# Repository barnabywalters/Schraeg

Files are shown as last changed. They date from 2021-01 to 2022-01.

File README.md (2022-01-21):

# Schräg

Schräg is an 8HP multimode filter module for the eurorack format, based off the [Bastl Cinnamon](https://bastl-instruments.com/eurorack/modules/cinnamon).

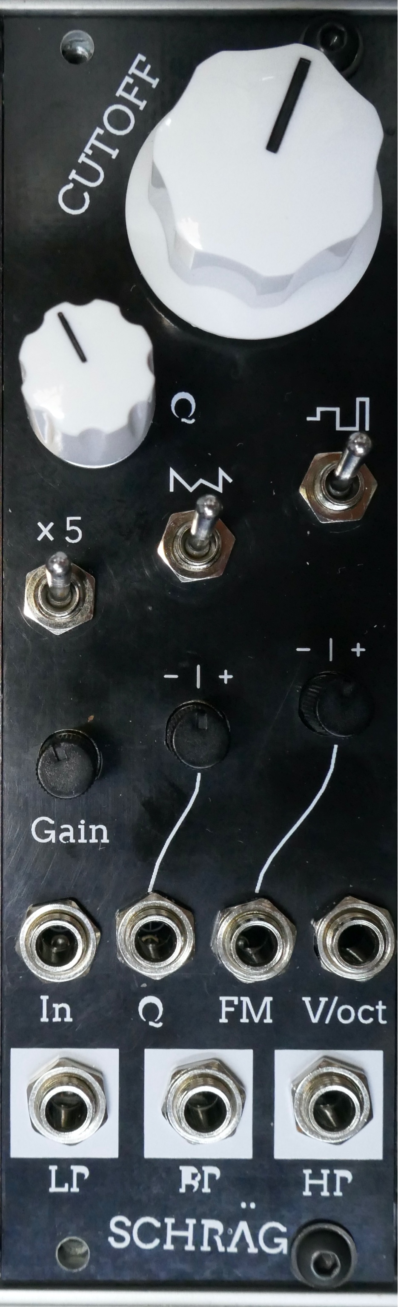
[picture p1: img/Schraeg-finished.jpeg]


## Smaller Warning and Disclaimer

As of 2021-03-01, at least one person has reported successfully building the current board revision. However, another builder reported a minor issue with the attenuverter circuits which prevents full-range voltage control over resonance (and limits voltage control over FM). This should be fixable only with component substitutions, we’re working on a fix. More information and updates [in the corresponding lines thread](https://llllllll.co/t/diy-module-release-schrag-bastl-cinnamon-rework/40590).

See the Changelog below for more updates and version-specific fixes.

## Quick links

* [Schematic](Schraeg/Schraeg.pdf)
* [Gerbers](Schraeg/output)
* [BOM](Schraeg/Schraeg%20BOM.csv)
* [Schräg on ModularGrid](https://www.modulargrid.net/e/other-unknown-schraeg)
* [Schräg release and Q&A thread on lines](https://llllllll.co/t/diy-module-release-schrag-bastl-cinnamon-rework/40590)

## Need help assembling your Schräg?

I can’t promise quick responses, but am happy to try to help out!

If you’re **having trouble or need help assembling or troubleshooting** a Schräg, please start a [discussion](https://github.com/barnabywalters/Schraeg/discussions/new).

If you’ve **found a specific error which needs fixing**, please file an [issue](https://github.com/barnabywalters/Schraeg/issues/new).

If you’re not sure which, start a discussion, and we’ll convert it into an issue if we can distill it into a concrete problem.

## Features

Schräg is effectively a repackaged Bastl Cinnamon:

* Multimode filter with independent outputs (2-pole LP, 2-pole HP, 1-pole BP)
* V/oct input
* Self-resonates for use as a sine oscillator
* Input with an attenuator and 5x gain switch
* Two character switches for altering the resonance tracking
* All-SMD construction in a DIY-friendly format, with 0603 handsoldering footprints, all components on the back of the circuit board
* Built mostly using standard and easily-available components

with a few modifications:

* larger 8HP form factor, allowing for a big juicy cutoff knob and larger character and gain switches
* Voltage control over resonance, through an attenuverter
* FM input through an attenuverter, which works as a pitch fine-tune control with nothing patched
* A bi-directional power connector, with polyfuses
* An Interactive BOM (`Schraeg/Output/Interactive BOM.html` once you’ve cloned the repo locally) to aid in part placement
* Schematics and PCB laid out using KiCAD

The additional functionality is achieved with a minimum of extra components, thanks to the two unused VCA cells in the original design.

## License

The schematic, board layout and graphics are released under a cc-by-sa license. [Bastl Instruments](https://bastl-instruments.com/) generously gave their permission for me to release my rework of their module. They’re a cool company. Go check out their work!

## Development

In 2019 I was looking through the [Bastl Cinnamon schematic](https://github.com/bastl-instruments/bastlSchematics/blob/master/CINNAMON_V1.2.pdf) and realised that it only uses two of the four available V2164D VCA cells.

At the time I needed PCB layout practise (and a filter module for my DIY eurorack!), so I ended up prototyping and building an 8HP version of cinnamon for myself which uses the two spare cells to implement voltage control over resonance, as well as a few other little additions listed above.

I called it “Schräg” because of both the angled panel design, the weird sounds possible with Bastl’s cool distortion circuits, and the strange way KiCAD mangled the panel graphics.

A bit more than a year after building the first Schräg, I finally got around to fixing the various small issues with the first board revision, and asking Bastl if they were okay with me open-sourcing the project. They were, and here we are.

## Changelog

### v0.2.1

* Fixed the LM4040 schematic symbols and PCB traces (#2)

### v0.2

* First version released to the public.
* These boards have an issue with the LM4040 orientation (see #2). Depending on the specific LM4040s, it may not cause any problems, but if building from scratch it’s best to install them correctly the first time. To fix it, solder the LM4040s at an angle so that pin 2 (NC) gets connected to pin 3 (5V Ref or GND, depending on the LM4040)

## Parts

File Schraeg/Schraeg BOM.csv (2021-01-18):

Reference | Quantity | Value | Footprint | Datasheet | Notes
AUDIO_IN1 BP_OUT1 FM_IN1 HP_OUT1 LP_OUT1 RES_CV1 V_OCT_IN1 | 7 | PJ301M-12 | Eurocad:PJ301M-12
C1 C12 C7 C8 | 4 | 560pF | Capacitor_SMD:C_0603_1608Metric_Pad1.05x0.95mm_HandSolder | ~
C10 C11 C13 | 3 | 220pF | Capacitor_SMD:C_0603_1608Metric_Pad1.05x0.95mm_HandSolder | ~
C14 C15 C18 | 3 | 220n | Capacitor_SMD:C_0603_1608Metric_Pad1.05x0.95mm_HandSolder | ~
C16 C17 | 2 | 22uF | Capacitor_SMD:CP_Elec_6.3x5.4 | ~
C19 C20 C21 C22 C23 C24 C25 C26 C27 C28 | 10 | 100n | Capacitor_SMD:C_0603_1608Metric_Pad1.05x0.95mm_HandSolder | ~
C2 C4 C5 C6 | 4 | 10uF | Capacitor_SMD:CP_Elec_5x4.5 | ~
C3 C9 | 2 | 100pF | Capacitor_SMD:C_0603_1608Metric_Pad1.05x0.95mm_HandSolder | ~
D1 D2 | 2 | 1N4148 | Diode_SMD:D_SOD-123 | ~
D3 | 1 | 5V | Diode_SMD:D_SOD-123 | ~ | 5V Zener diode
D5 | 1 | MB2S | Package_TO_SOT_SMD:TO-269AA | http://www.vishay.com/docs/88661/mb2s.pdf
D4 D6 | 2 | LM4040DCK-5 | Package_TO_SOT_SMD:SOT-23_Handsoldering | http://www.ti.com/lit/ds/symlink/lm4040-n.pdf
F1 F2 | 2 | Polyfuse | Fuse:Fuse_1206_3216Metric_Pad1.42x1.75mm_HandSolder | ~ | PPTC fuse of your choice, e.g. 1206L012WR
CUTOFF1 FM_ATTV1 INPUT_GAIN1 RESONANCE1 RES_ATTV1 | 5 | 100k | Eurocad:Alpha9mmPot | ~ | Any 100k 9mm pot should work
PWR_IN1 | 1 | EURO_PWR_2x5 | Connector_PinHeader_2.54mm:PinHeader_2x05_P2.54mm_Vertical
R14 R40 | 2 | 15K | Resistor_SMD:R_0603_1608Metric_Pad1.05x0.95mm_HandSolder | ~
R15 R30 R32 R39 | 4 | 470R | Resistor_SMD:R_0603_1608Metric_Pad1.05x0.95mm_HandSolder | ~
R18 | 1 | 22k | Resistor_SMD:R_0603_1608Metric_Pad1.05x0.95mm_HandSolder | ~
R19 R22 | 2 | 47k | Resistor_SMD:R_0603_1608Metric_Pad1.05x0.95mm_HandSolder | ~
R21 | 1 | 10k | Resistor_SMD:R_0603_1608Metric_Pad1.05x0.95mm_HandSolder | ~
R23 R24 R25 | 3 | 1K | Resistor_SMD:R_0603_1608Metric_Pad1.05x0.95mm_HandSolder | ~
R26 | 1 | 330K | Resistor_SMD:R_0603_1608Metric_Pad1.05x0.95mm_HandSolder | ~
R27 R28 R29 R31 R33 R34 R35 R36 R38 | 9 | 33k | Resistor_SMD:R_0603_1608Metric_Pad1.05x0.95mm_HandSolder | ~
R1 R10 R11 R12 R13 R16 R17 R2 R20 R3 R4 R5 R6 R7 R8 R9 | 16 | 100k | Resistor_SMD:R_0603_1608Metric_Pad1.05x0.95mm_HandSolder | ~
R41 | 1 | 1.5K | Resistor_SMD:R_0603_1608Metric_Pad1.05x0.95mm_HandSolder | ~
R43 | 1 | 470K | Resistor_SMD:R_0603_1608Metric_Pad1.05x0.95mm_HandSolder | ~
R46 | 1 | 3.3K | Resistor_SMD:R_0603_1608Metric_Pad1.05x0.95mm_HandSolder | ~
R44 R47 | 2 | 6.8K | Resistor_SMD:R_0603_1608Metric_Pad1.05x0.95mm_HandSolder | ~
R37 R42 R45 R48 R49 | 5 | 100K | Resistor_SMD:R_0603_1608Metric_Pad1.05x0.95mm_HandSolder | ~
RES_ADJ1 | 1 | 250K | Potentiometer_THT:Potentiometer_Bourns_3296W_Vertical | ~
RV_SAW_OCTAVE1 | 1 | 100k | Potentiometer_THT:Potentiometer_Bourns_3296W_Vertical | ~
SW_DRIVE1 SW_RES_DIST1 SW_WOBBLE1 | 3 | SW_SPDT | Connector_PinHeader_2.54mm:PinHeader_1x03_P2.54mm_Vertical | ~ | SPDT switches with 0.1” pin spacing. These Dailywells from Thonk work: https://www.thonk.co.uk/shop/sub-mini-toggle-switches/
U1 U2 U4 U5 | 4 | TL074 | Package_SO:SOIC-14_3.9x8.7mm_P1.27mm | http://www.ti.com/lit/ds/symlink/tl071.pdf
U3 | 1 | V2164 | Package_SO:SOIC-16_3.9x9.9mm_P1.27mm
V_OCT_SCALE1 | 1 | 5K | Potentiometer_THT:Potentiometer_Bourns_3296W_Vertical | ~

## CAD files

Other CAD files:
Schraeg Panel Graphics.dxf
Schraeg Panel Graphics 40.64 x 128.5.dxf

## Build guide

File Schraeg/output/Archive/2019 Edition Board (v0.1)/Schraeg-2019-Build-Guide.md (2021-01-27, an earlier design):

# Schräg 2019 Edition (v0.1) Build Guide

If you’re reading this, odds are you’re one of the 10 people who got my spare boards from the first run of Schräg PCBs and panels. If that’s not the case, you probably want the build guide for the current edition (2021, v0.2 or later).

Refer to the interactive HTML BOM for part placement help (`./ibom.html`).

Refer to the [Bastl Cinnamon Assembly guide](https://bastl-instruments.com/content/files/cinnamon-1.2-assembly-guide.pdf) for calibration once assembly is complete. But please **don’t bother the good people at Bastl if you have problems with your Schräg**. Instead, ask the person you got your board from, online communities explicitly for DIY synth help, or [Barnaby](https://waterpigs.co.uk).

## BOM Changes

Use the BOM provided for the 2021 edition, with the following exceptions or caveats.

The three SPDT switches are the less common subminiature ones with 0.1" pin spacing, sold by Thonk and presumably also available elsewhere.

In the first run of boards I made the mistake of using SC-70 footprints for the two LM4040s, rather than the more common and easier to handle SOT-23 footprints. There are two ways to deal with this: either buy LM4040s in SC-70 packages, or solder the regular SOT-23 ones on backwards as shown:

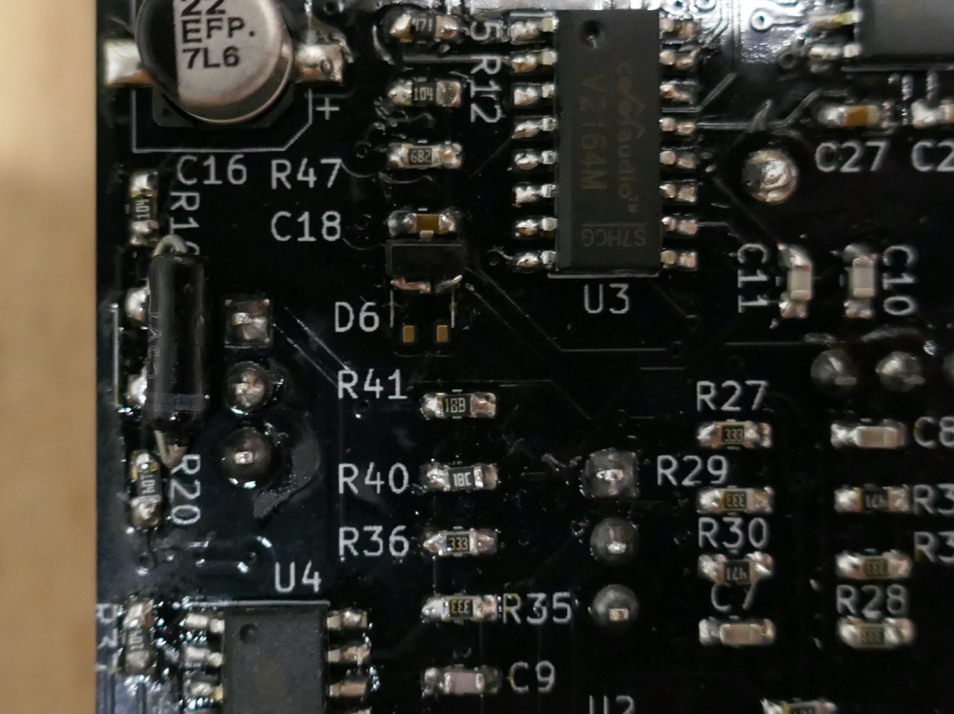
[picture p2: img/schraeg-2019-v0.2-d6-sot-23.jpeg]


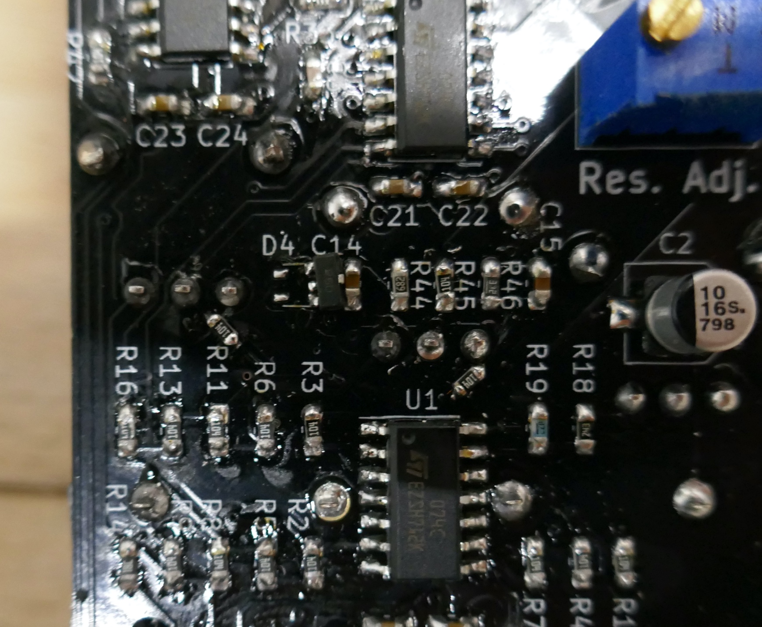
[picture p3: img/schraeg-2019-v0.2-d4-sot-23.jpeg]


In case it’s not clear: the SOT-23s are upside-down, and their two active pins soldered to the two outside pads on the outsides of the 3-padded side of the SC-70 footprint. Consult the LM4040 datasheet for more information.

## Front panel changes

The D-holes for the subminiature toggle switches are slightly undersize, and will likely require filing the flat side. Please wear breath protection while filing the PCB and panel!

The panel holes for the 3.5mm jacks are slightly oversize. If you’re picky about getting the jacks perfectly aligned, it will require some extra care when positioning and soldering them.

## Circuit changes

I forgot two 100k 0603 resistors in the 2019 edition, and you will need to cut some traces and install them yourself if you want the attenuverters for voltage control of resonance and FM to work properly.

Cut the following traces close to R11 and R19:

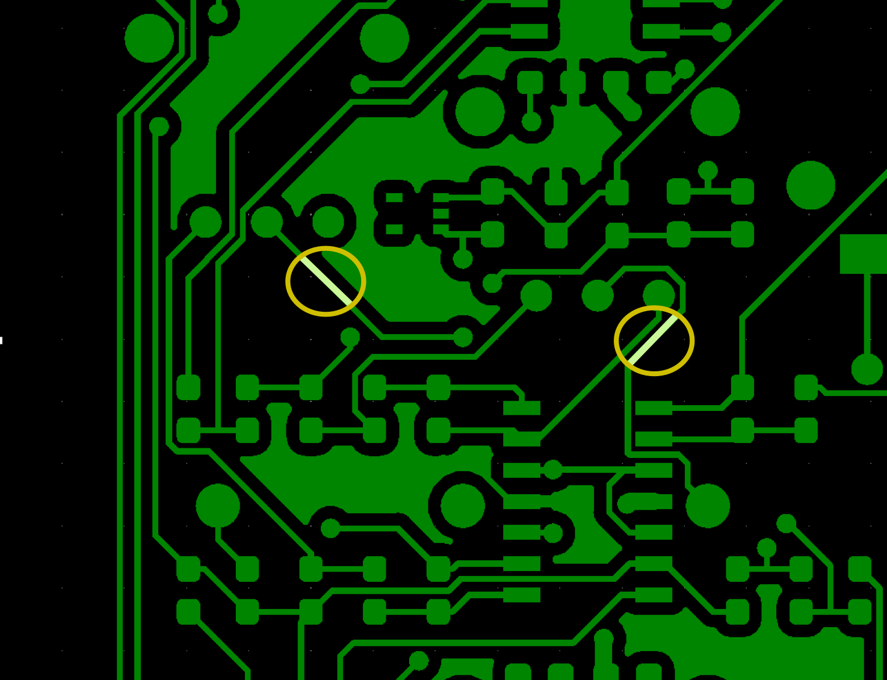
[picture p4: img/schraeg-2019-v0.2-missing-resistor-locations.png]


Scrape a few millimetres of copper away completely, and then scrape pads clear for your choice of 100k SMD resistors.

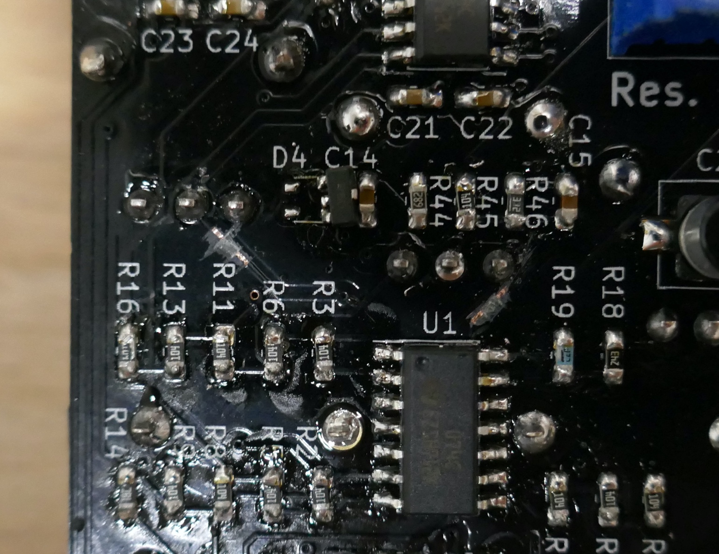
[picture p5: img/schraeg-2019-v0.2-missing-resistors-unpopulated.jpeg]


Populate the resistors, and use a multimeter to check that the traces have successfully been replaced with 100k resistances.

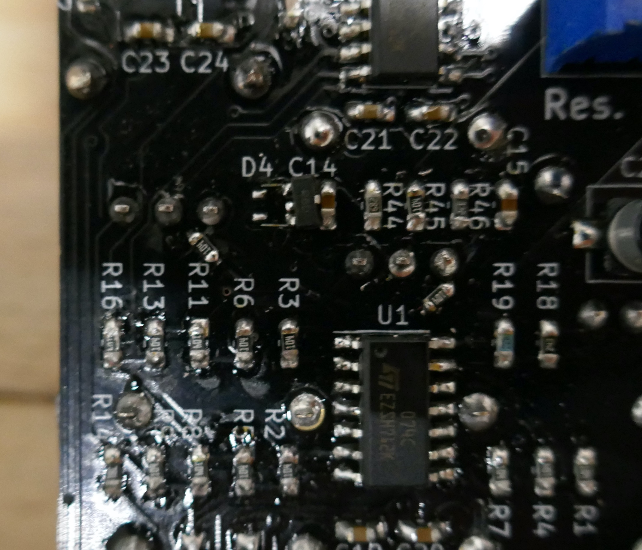
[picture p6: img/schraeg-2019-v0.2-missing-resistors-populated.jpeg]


## Miscellaneous Changes

I got the footprints of the toggle switches the “wrong way round”, resulting in each function being active in the upper position rather than the lower position I had intended. This has been changed on later editions, but is not really a big problem.

## Troubleshooting and known problems

If you don’t install the missing 100k resistors correctly, the two attenuverters will behave strangely, working okay on in the positive direction but backwards in the negative direction.

Other known problems and their corresponding solutions will be added here as necessary.

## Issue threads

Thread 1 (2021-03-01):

Attenuverter circuits don’t allow voltage control over the full range of Resonance and FM

barnabywalters, 2021-03-01:
From [discussion on lines](https://llllllll.co/t/diy-module-release-schrag-bastl-cinnamon-rework/40590):

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

barnabywalters, 2021-03-01:
This is my fault for copy/pasting the attenuverter schematic without fully understanding or testing it, and seeing that it worked on the completed module without fully testing it.

It should be fixable with a few simple component substitutions rather than requiring a rewire. Here are some simulated values which should at least improve things ([from this lines comment](https://llllllll.co/t/diy-module-release-schrag-bastl-cinnamon-rework/40590/8?u=barnaby)):

* R48 → 1k
* R2 → 1k
* R5 → 10k
* FM_ATTV1 remains at 100k

eh2k, 2021-06-08:
Hello Barnaby,
I have built it with the listed resistor values. But something is wrong with the resonnance/q cv.
Imho it would be helpfull, if you could provide the following messurement values (or calculated):

* **Q CV Jack "empty/0V"  -> Q-attenuverter Mid position (all Switches up)**
  * RES_CV Voltage on Pin 1 on U2 when Resonance-Pot is on Min Position:
  * .......................................................................................................................Max Position:

* **Q CV Jack "5V"  -> Q-attenuverter Min position (all Switches up)**
  * RES_CV Voltage on Pin 1 on U2 when Resonance-Pot is on Min Position:
  * .......................................................................................................................Max Position:

* **Q CV Jack "5V"  -> Q-attenuverter Max position (all Switches up)**
  * RES_CV Voltage on Pin 1 on U2 when Resonance-Pot is on Min Position:
  * .......................................................................................................................Max Position:

As I unterstand, the RES_CV Voltage should be in all cases in the range 0 to 5V ?
Maybe it will help to understand the -5V reference vca-loop/feedback function.

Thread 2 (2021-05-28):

LM4040 - wrong pinout?

ultrapalace, 2021-05-28:
The two LM4040s have footprints with anode at pin1 and cathode at pin 3. In the SOT23 package, the actual anode is on pin 2, with the cathode on pin 1, and pin 3 must be connected to anode or left floating. Rotating my LM4040's clockwise allows generation of the proper 5V and -5V references.

I have not yet found an LM4040 with a footprint as is drawn in the circuit, but if there's one that works, please update the BOM to specify that one.

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

barnabywalters, 2021-05-28:
Well spotted! I think this was caused by the switch from the old LM4040 package and the new one. I made the mistake of assuming that KiCAD would correctly map the old schematic symbols to the new footprints, but it didn’t, and I had to swap out the schematic symbol too.

It looks like this may have been working already in some cases as “Pin 3 is attached to substrate and must be connected to ANODE or left open.“, which would explain why the module worked well enough already, and I didn’t notice any problems.

ultrapalace, 2021-05-28:
Wow that was a quick update!! I think it may be luck of the draw for which
LM4040s have the pin 3 connected to the substrate, the one I used does not
have that connection, so my reference was -9V and +9V on the -5 and +5.

On Fri, May 28, 2021 at 11:02 AM Barnaby Walters ***@***.***>
wrote:

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

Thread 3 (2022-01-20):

Dioide Polarity??

Alexcoleman268, 2022-01-20:
What is the polarity of the diodes on D1 and D2? Theres no mark on the PCB and i cant find any pictures??

barnabywalters, 2022-01-21:
The polarity is indicated on the silkscreen, but KiCAD’s method for doing so is, uh, “minimal” (same for ICs — in the future I will try to use better silkscreen graphics). Here’s a photo showing correct orientations of the diodes:

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

Alexcoleman268, 2022-01-21:
Thanks! I ended up checking some post on Lines and figured it out, I built my module though and sadly its not working, All my soldering is great I have a ton of SMD experience, Is there anything on the V 2.0 boards from pusherman I need to do differently than just build as is? I know there were some problems with a couple of the boards.

Thanks a ton!
Alex

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

barnabywalters, 2022-01-21:
Sorry to hear its not working! If you have a v0.2.0 board I can think of two known issues.

The old layout only worked as-is with certain LM4040s, but can be fixed by soldering the LM4040s at a funny angle so that the correct pins meet the correct pads:

https://github.com/barnabywalters/Schraeg#v02
https://github.com/barnabywalters/Schraeg/issues/2

Also, apparently I got the rectifier symbol mixed up, which could lead to the module only getting powered with the power connector in one of the two possible orientations, as described here: https://llllllll.co/t/diy-module-release-schrag-bastl-cinnamon-rework/40590/23

If neither of those fix things, best thing to do would be to debug it as far as you can get by yourself (e.g. checking voltage supply rails, reference rails, tracing the signal path and figuring out where it stops), let me know what you find, and I’ll help as best I can.

Closed 2022-01-21.

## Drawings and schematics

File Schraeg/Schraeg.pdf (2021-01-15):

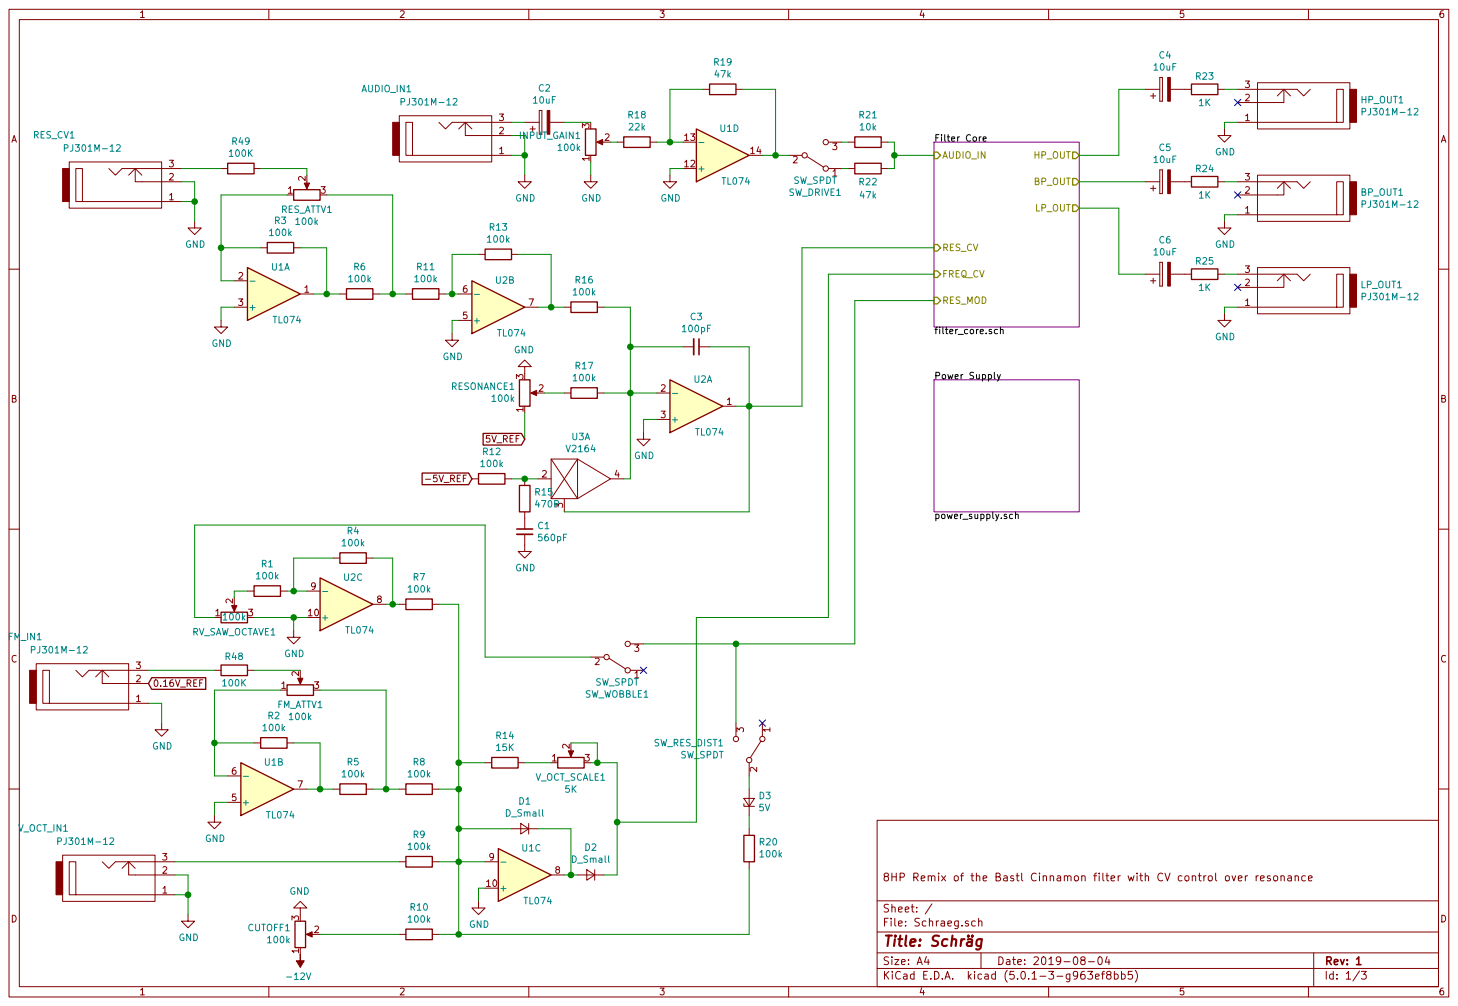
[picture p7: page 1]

File: Schraeg.sch Sheet: / 8HP Remix of the Bastl Cinnamon filter with CV control over resonance

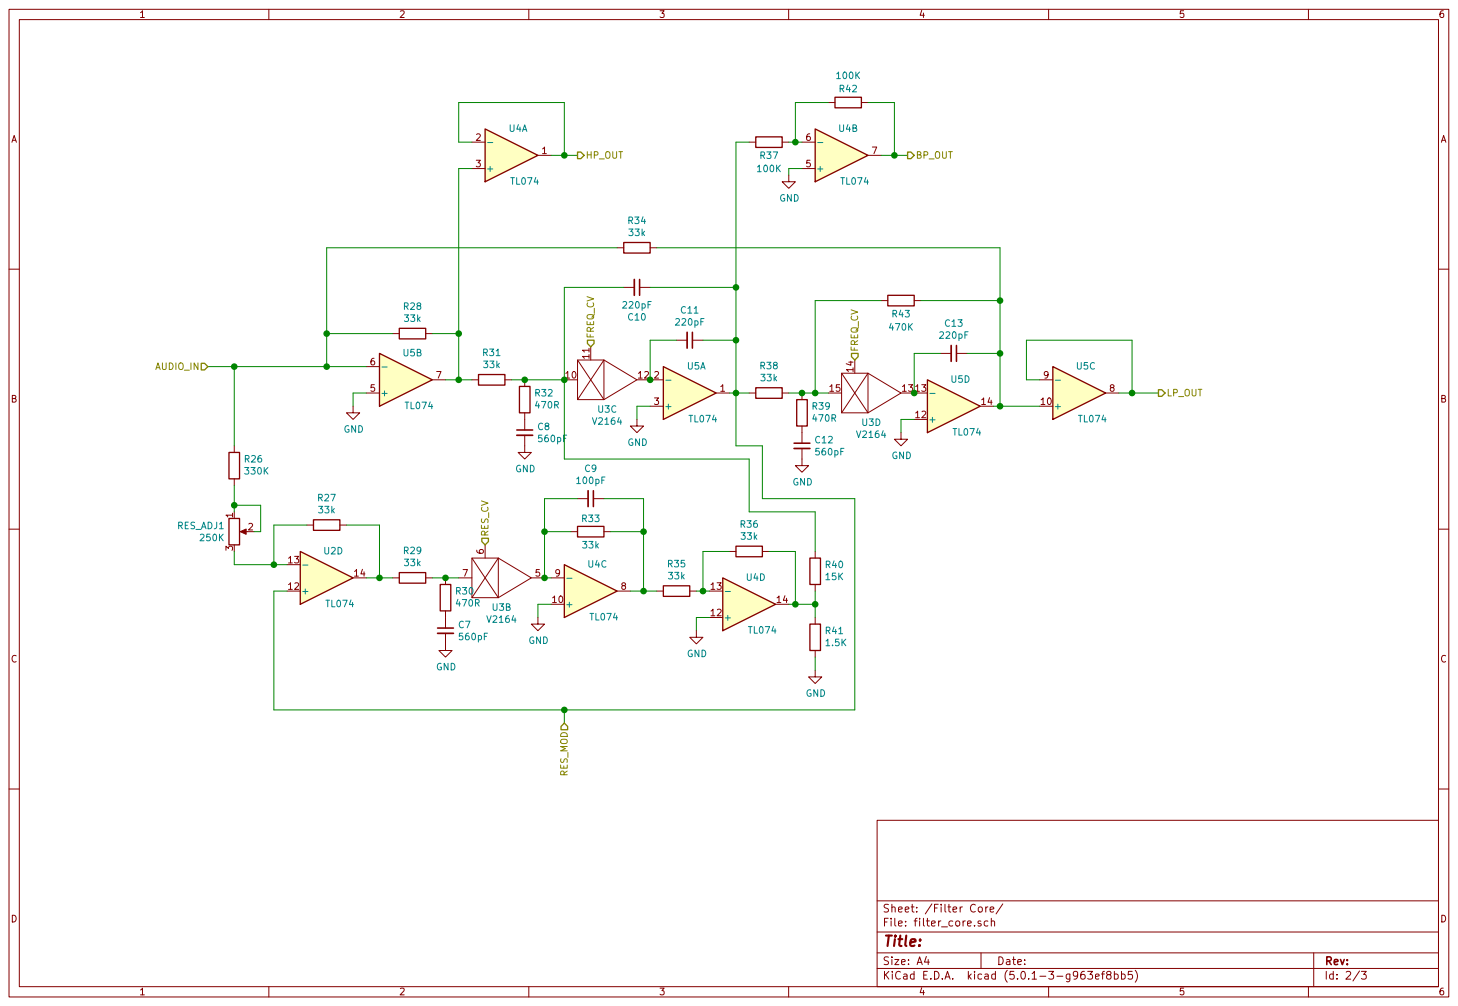
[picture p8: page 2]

File: filter_core.sch Sheet: /Filter Core/
Id: 2/3 Title:

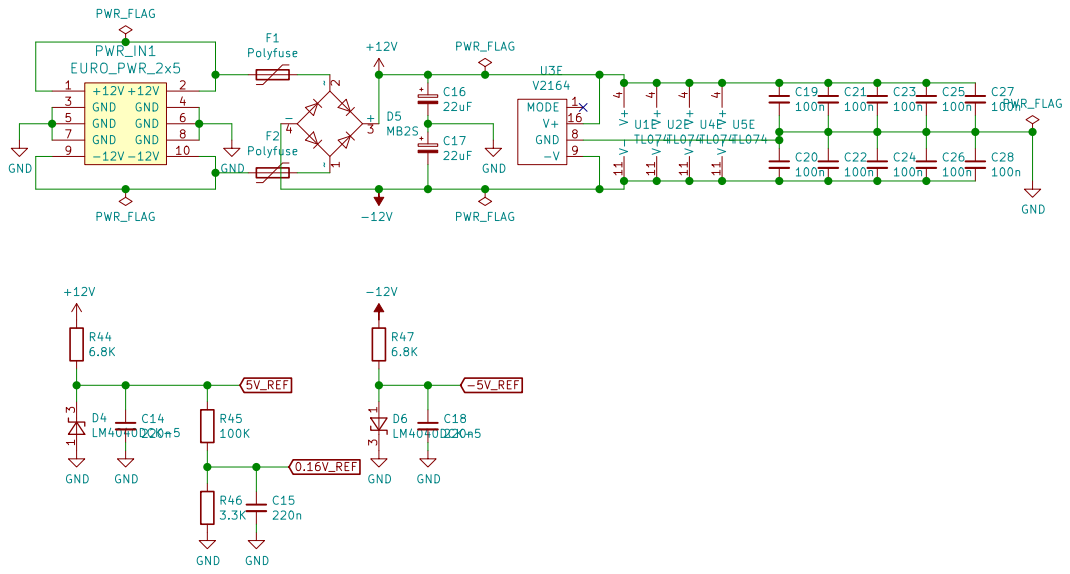
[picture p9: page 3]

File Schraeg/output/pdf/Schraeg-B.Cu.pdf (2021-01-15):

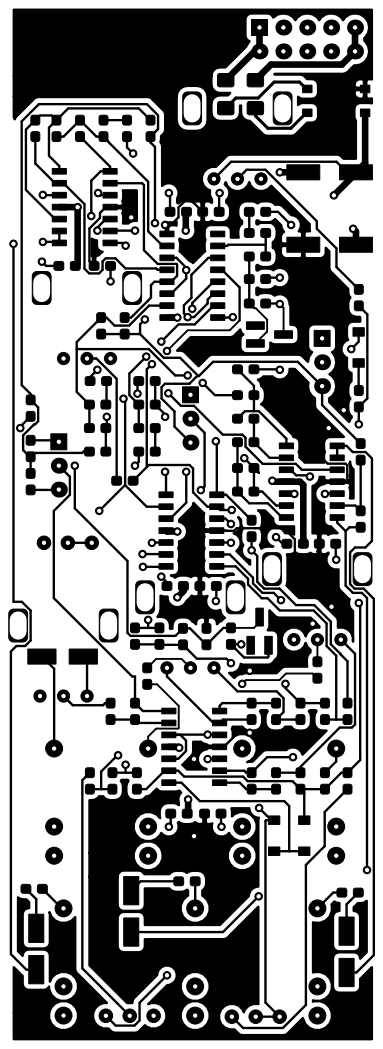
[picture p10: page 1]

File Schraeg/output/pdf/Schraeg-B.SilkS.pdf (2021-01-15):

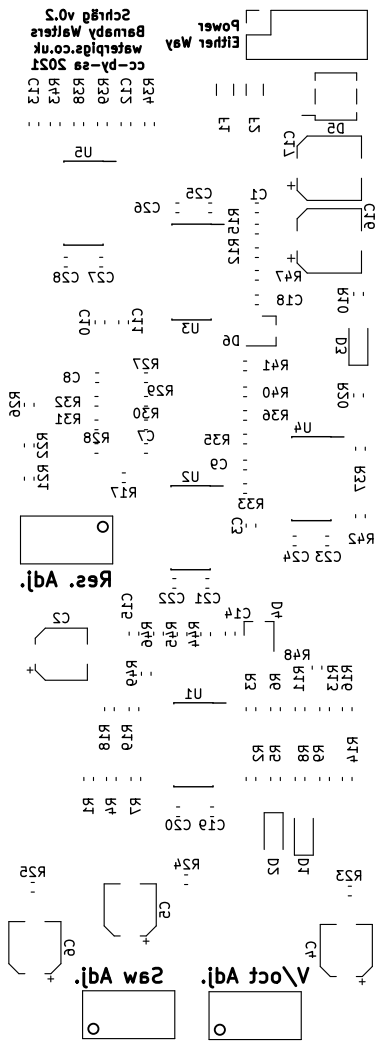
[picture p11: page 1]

cc-by-sa 2021 Power Either Way Res. Adj.

Schräg v0.2 Barnaby Walters waterpigs.co.uk

Saw Adj. V/oct Adj. U3 C1 C2 C3 C4 C5 C6 C7 C8 C9 C10 C11 C13 C12 C14 C15 C16 C17 C18 C20 C19 C22 C21 C24 C23 C25 C26 C28 C27 D2 D1 D3 D5 F1F2 R1 R2 R3 R4 R5 R6 R7 R8 R9 R10 R11 R12 R13 R14 R15 R16 R17 R18 R19 R20 R21 R22 R23 R24 R25R26 R27 R28 R29R30 R31 R32 R33 R34 R35 R36 R37 R38 R39 R40 R41 R42 R43 R46 R45 R44 R47 U1U2 U4 U5 D4 D6 R49 R48

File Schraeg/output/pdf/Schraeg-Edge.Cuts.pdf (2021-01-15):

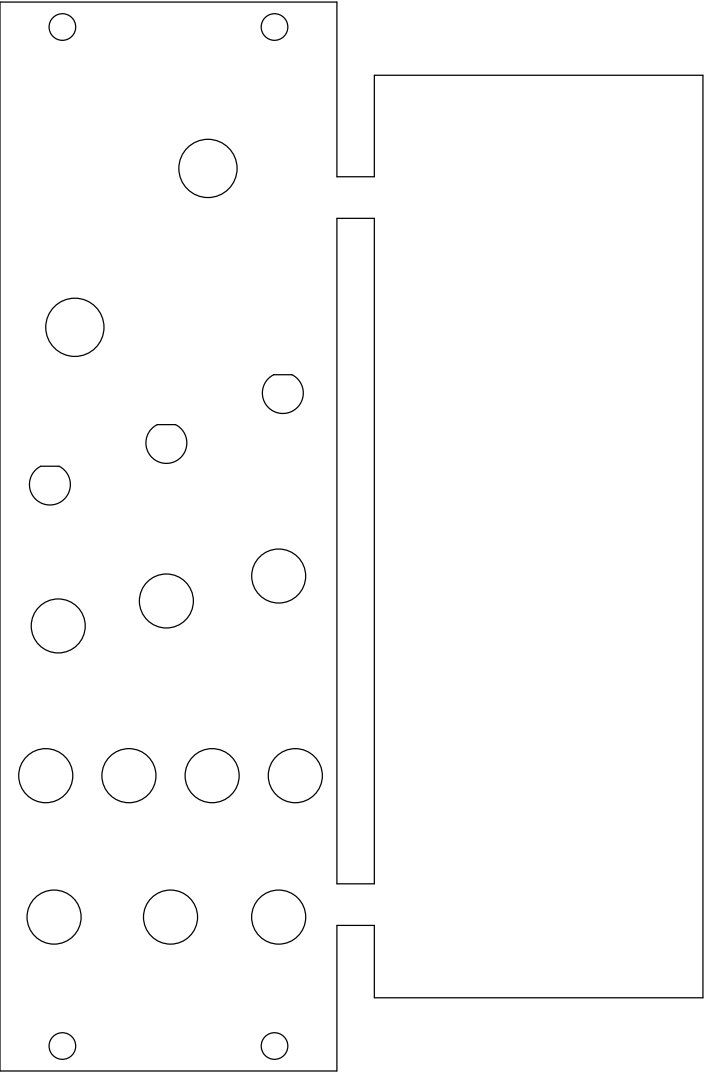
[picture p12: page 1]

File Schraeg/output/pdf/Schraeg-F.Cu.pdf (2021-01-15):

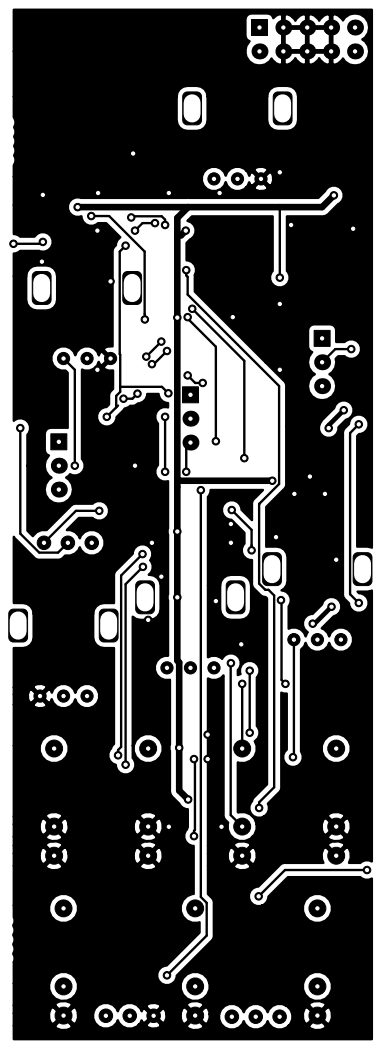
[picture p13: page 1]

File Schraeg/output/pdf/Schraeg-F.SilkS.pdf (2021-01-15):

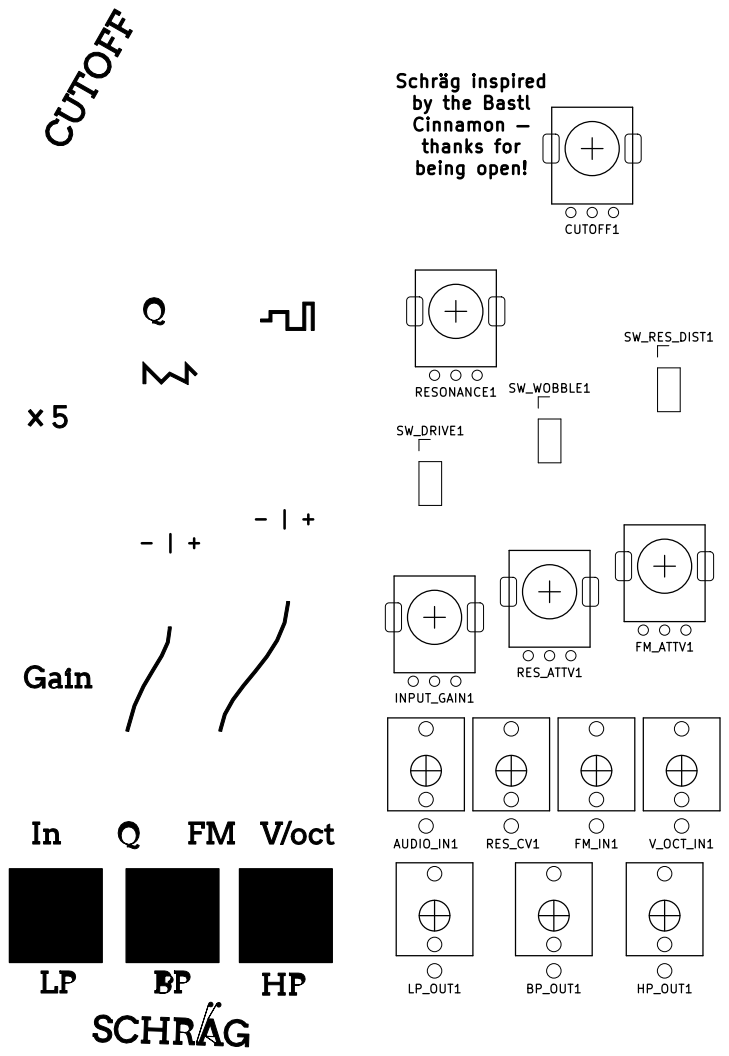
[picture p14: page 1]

Schräg inspired
by the Bastl Cinnamon thanks for being open!
FM_ATTV1 CUTOFF1

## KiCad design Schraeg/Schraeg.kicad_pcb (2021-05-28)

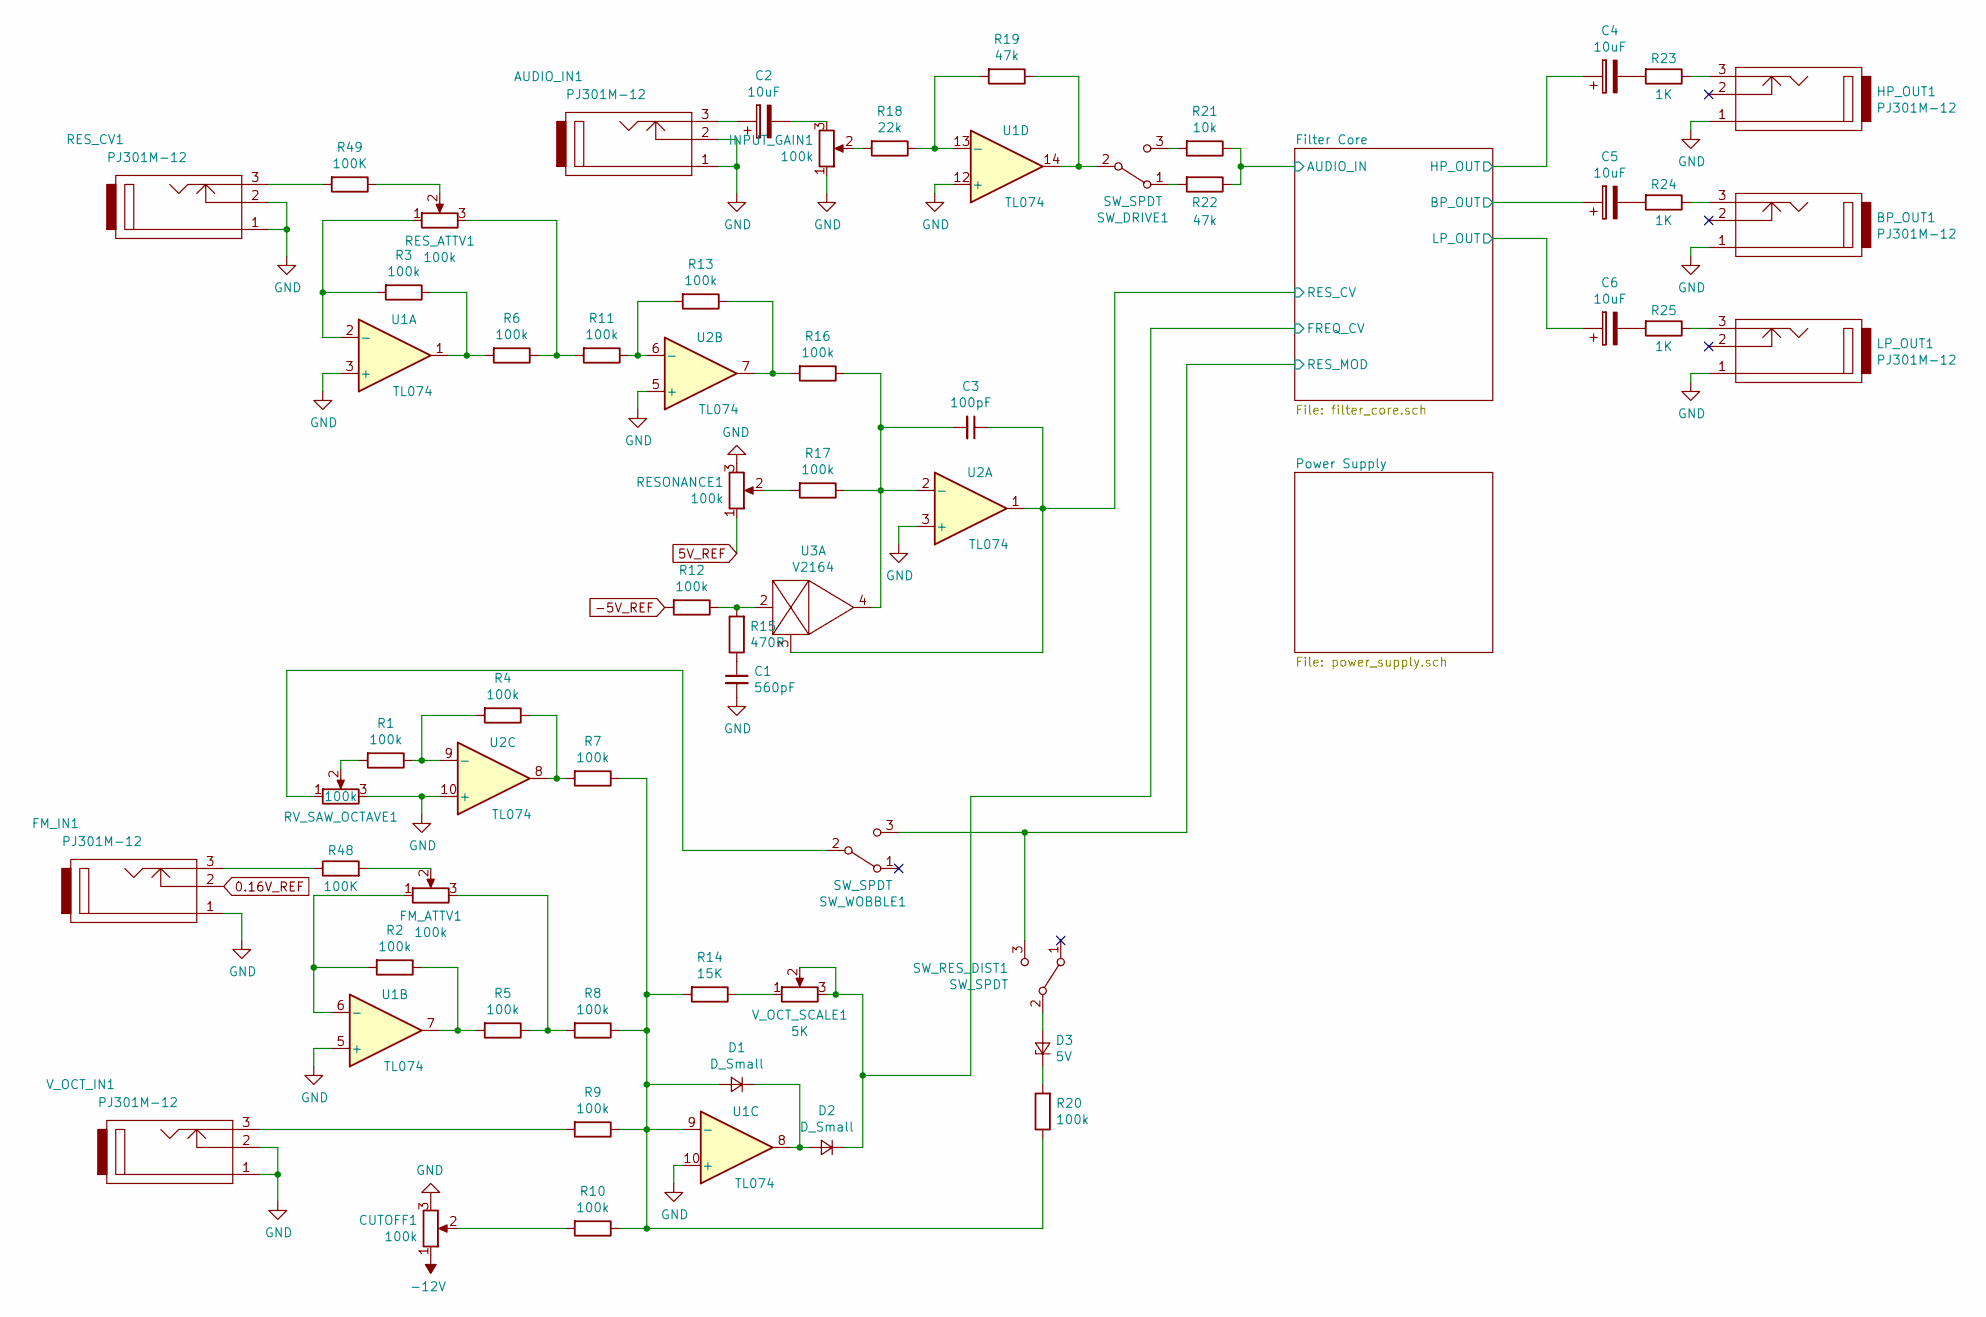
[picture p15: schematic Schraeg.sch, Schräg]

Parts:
AUDIO_IN1: PJ301M-12
BP_OUT1: PJ301M-12
C1: 560pF; C_0603_1608Metric_Pad1.05x0.95mm_HandSolder
C2, C4, C5, C6: 10uF; CP_Elec_5x4.5
C3: 100pF; C_0603_1608Metric_Pad1.05x0.95mm_HandSolder
CUTOFF1: 100k; Alpha9mmPot
D1, D2: D_Small; D_SOD-123
D3: 5V; D_SOD-123
FM_ATTV1: 100k; Alpha9mmPot
FM_IN1: PJ301M-12
HP_OUT1: PJ301M-12
INPUT_GAIN1: 100k; Alpha9mmPot
LP_OUT1: PJ301M-12
R1, R2, R3, R4, R5, R6, R7, R8, R9, R10, R11, R12, R13, R16, R17, R20: 100k; R_0603_1608Metric_Pad1.05x0.95mm_HandSolder
R14: 15K; R_0603_1608Metric_Pad1.05x0.95mm_HandSolder
R15: 470R; R_0603_1608Metric_Pad1.05x0.95mm_HandSolder
R18: 22k; R_0603_1608Metric_Pad1.05x0.95mm_HandSolder
R19, R22: 47k; R_0603_1608Metric_Pad1.05x0.95mm_HandSolder
R21: 10k; R_0603_1608Metric_Pad1.05x0.95mm_HandSolder
R23, R24, R25: 1K; R_0603_1608Metric_Pad1.05x0.95mm_HandSolder
R48, R49: 100K; R_0603_1608Metric_Pad1.05x0.95mm_HandSolder
RESONANCE1: 100k; Alpha9mmPot
RES_ATTV1: 100k; Alpha9mmPot
RES_CV1: PJ301M-12
RV_SAW_OCTAVE1: 100k; Potentiometer_Bourns_3296W_Vertical
SW_DRIVE1: SW_SPDT; PinHeader_1x03_P2.54mm_Vertical
SW_RES_DIST1: SW_SPDT; PinHeader_1x03_P2.54mm_Vertical
SW_WOBBLE1: SW_SPDT; PinHeader_1x03_P2.54mm_Vertical
U1, U2: TL074; SOIC-14_3.9x8.7mm_P1.27mm
U3: V2164; SOIC-16_3.9x9.9mm_P1.27mm
V_OCT_IN1: PJ301M-12
V_OCT_SCALE1: 5K; Potentiometer_Bourns_3296W_Vertical

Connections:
0.16V_REF: FM_IN1.2; also elsewhere on the board
5V_REF: RESONANCE1.1; also elsewhere on the board
-5V_REF: R12.2; also elsewhere on the board
-12V: CUTOFF1.1; also elsewhere on the board
/Filter Core/AUDIO_IN: R21.1, R22.1; also elsewhere on the board
/Filter Core/BP_OUT: C5.1; also elsewhere on the board
/Filter Core/FREQ_CV: D2.1 (K), V_OCT_SCALE1.2, V_OCT_SCALE1.3; also elsewhere on the board
/Filter Core/HP_OUT: C4.1; also elsewhere on the board
/Filter Core/LP_OUT: C6.1; also elsewhere on the board
/Filter Core/RES_CV: C3.1, U2.1, U3.3; also elsewhere on the board
/Filter Core/RES_MOD: SW_RES_DIST1.3 (C), SW_WOBBLE1.3 (C); also elsewhere on the board
GND: AUDIO_IN1.1, AUDIO_IN1.2, BP_OUT1.1, C1.2, CUTOFF1.3, FM_IN1.1, HP_OUT1.1, INPUT_GAIN1.1, LP_OUT1.1, RESONANCE1.3, RES_CV1.1, RES_CV1.2, RV_SAW_OCTAVE1.3, U1.3 (+), U1.5 (+), U1.10 (+), U1.12 (+), U2.3 (+), U2.5 (+), U2.10 (+), V_OCT_IN1.1, V_OCT_IN1.2; also elsewhere on the board
unnamed: AUDIO_IN1.3, C2.1
unnamed: BP_OUT1.3, R24.1
unnamed: C1.1, R15.1
unnamed: C2.2, INPUT_GAIN1.3
unnamed: C3.2, R16.1, R17.1, U2.2 (-), U3.4
unnamed: C4.2, R23.2
unnamed: C5.2, R24.2
unnamed: C6.2, R25.2
unnamed: CUTOFF1.2, R10.2
unnamed: D1.1 (K), D2.2 (A), U1.8
unnamed: D1.2 (A), R7.1, R8.1, R9.1, R10.1, R14.2, R20.1, U1.9 (-)
unnamed: D3.1 (K), R20.2
unnamed: D3.2 (A), SW_RES_DIST1.2 (B)
unnamed: FM_ATTV1.1, R2.2, U1.6 (-)
unnamed: FM_ATTV1.2, R48.2
unnamed: FM_ATTV1.3, R5.1, R8.2
unnamed: FM_IN1.3, R48.1
unnamed: HP_OUT1.3, R23.1
unnamed: INPUT_GAIN1.2, R18.2
unnamed: LP_OUT1.3, R25.1
unnamed: R1.1, R4.2, U2.9 (-)
unnamed: R1.2, RV_SAW_OCTAVE1.2
unnamed: R2.1, R5.2, U1.7
unnamed: R3.1, R6.2, U1.1
unnamed: R3.2, RES_ATTV1.1, U1.2 (-)
unnamed: R4.1, R7.2, U2.8
unnamed: R9.2, V_OCT_IN1.3
unnamed: R11.1, R13.2, U2.6 (-)
unnamed: R6.1, R11.2, RES_ATTV1.3
unnamed: R12.1, R15.2, U3.2
unnamed: R13.1, R16.2, U2.7
unnamed: R14.1, V_OCT_SCALE1.1
unnamed: R17.2, RESONANCE1.2
unnamed: R18.1, R19.2, U1.13 (-)
unnamed: R19.1, SW_DRIVE1.2 (B), U1.14
unnamed: R21.2, SW_DRIVE1.3 (C)
unnamed: R22.2, SW_DRIVE1.1 (A)
unnamed: R49.1, RES_ATTV1.2
unnamed: R49.2, RES_CV1.3
unnamed: RV_SAW_OCTAVE1.1, SW_WOBBLE1.2 (B)

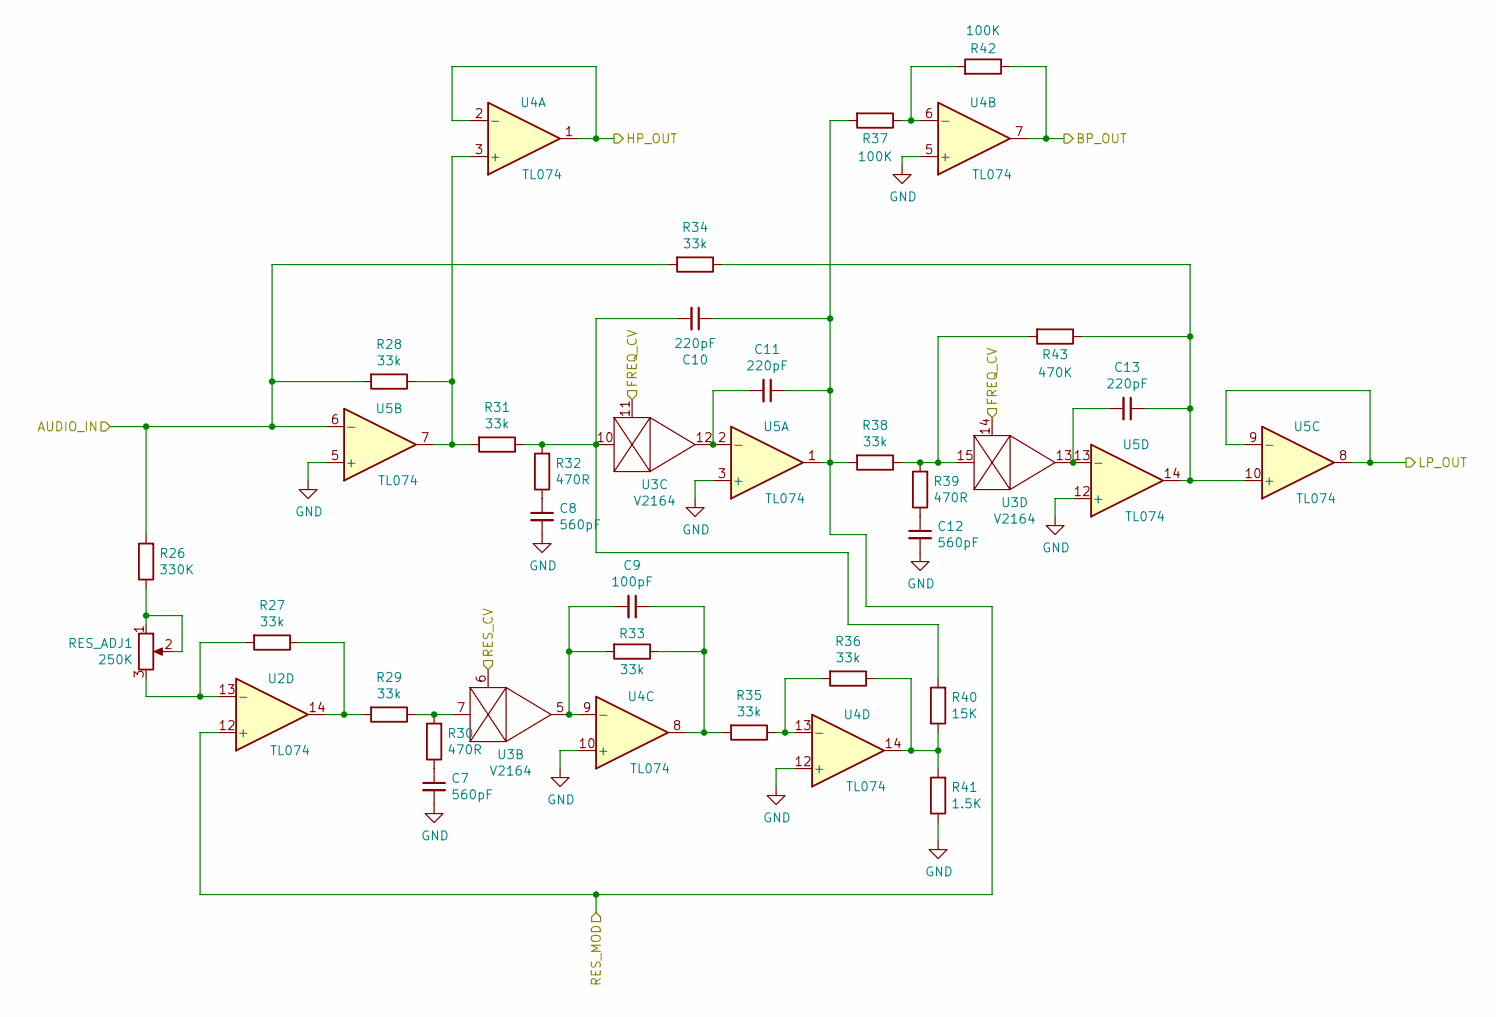
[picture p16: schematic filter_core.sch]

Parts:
C7, C8, C12: 560pF; C_0603_1608Metric_Pad1.05x0.95mm_HandSolder
C9: 100pF; C_0603_1608Metric_Pad1.05x0.95mm_HandSolder
C10, C11, C13: 220pF; C_0603_1608Metric_Pad1.05x0.95mm_HandSolder
R26: 330K; R_0603_1608Metric_Pad1.05x0.95mm_HandSolder
R27, R28, R29, R31, R33, R34, R35, R36, R38: 33k; R_0603_1608Metric_Pad1.05x0.95mm_HandSolder
R30, R32, R39: 470R; R_0603_1608Metric_Pad1.05x0.95mm_HandSolder
R37, R42: 100K; R_0603_1608Metric_Pad1.05x0.95mm_HandSolder
R40: 15K; R_0603_1608Metric_Pad1.05x0.95mm_HandSolder
R41: 1.5K; R_0603_1608Metric_Pad1.05x0.95mm_HandSolder
R43: 470K; R_0603_1608Metric_Pad1.05x0.95mm_HandSolder
RES_ADJ1: 250K; Potentiometer_Bourns_3296W_Vertical
U2, U4, U5: TL074; SOIC-14_3.9x8.7mm_P1.27mm
U3: V2164; SOIC-16_3.9x9.9mm_P1.27mm

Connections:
/Filter Core/AUDIO_IN: R26.2, R28.2, R34.2, U5.6 (-); also elsewhere on the board
/Filter Core/BP_OUT: R42.1, U4.7; also elsewhere on the board
/Filter Core/FREQ_CV: U3.11, U3.14; also elsewhere on the board
/Filter Core/HP_OUT: U4.1, U4.2 (-); also elsewhere on the board
/Filter Core/LP_OUT: U5.8, U5.9 (-); also elsewhere on the board
/Filter Core/RES_CV: U3.6; also elsewhere on the board
/Filter Core/RES_MOD: C10.1, C11.1, R37.2, R38.2, U2.12 (+), U5.1; also elsewhere on the board
GND: C7.2, C8.2, C12.2, R41.1, U4.5 (+), U4.10 (+), U4.12 (+), U5.3 (+), U5.5 (+), U5.12 (+); also elsewhere on the board
unnamed: C7.1, R30.1
unnamed: C8.1, R32.1
unnamed: C9.1, R33.1, R35.2, U4.8
unnamed: C9.2, R33.2, U3.5, U4.9 (-)
unnamed: C10.2, R31.1, R32.2, R40.2, U3.10
unnamed: C11.2, U3.12, U5.2 (-)
unnamed: C12.1, R39.1
unnamed: C13.1, R34.1, R43.1, U5.10 (+), U5.14
unnamed: C13.2, U3.13, U5.13 (-)
unnamed: R26.1, RES_ADJ1.1, RES_ADJ1.2
unnamed: R27.1, R29.2, U2.14
unnamed: R27.2, RES_ADJ1.3, U2.13 (-)
unnamed: R28.1, R31.2, U4.3 (+), U5.7
unnamed: R29.1, R30.2, U3.7
unnamed: R35.1, R36.2, U4.13 (-)
unnamed: R36.1, R40.1, R41.2, U4.14
unnamed: R37.1, R42.2, U4.6 (-)
unnamed: R38.1, R39.2, R43.2, U3.15

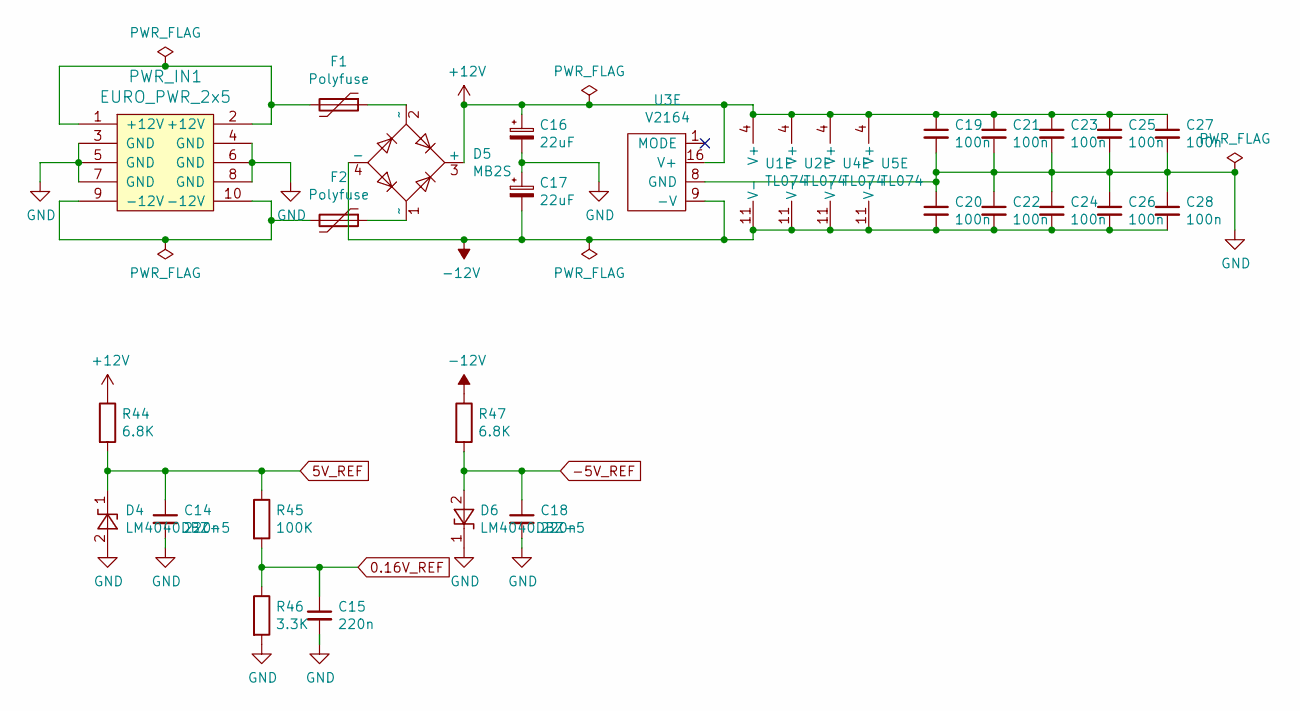
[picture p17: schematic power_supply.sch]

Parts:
C14, C15, C18: 220n; C_0603_1608Metric_Pad1.05x0.95mm_HandSolder
C16, C17: 22uF; CP_Elec_6.3x5.4
C19, C20, C21, C22, C23, C24, C25, C26, C27, C28: 100n; C_0603_1608Metric_Pad1.05x0.95mm_HandSolder
D4, D6: LM4040DBZ-5; SOT-23
D5: MB2S; TO-269AA
F1, F2: Polyfuse; Fuse_1206_3216Metric_Pad1.42x1.75mm_HandSolder
PWR_IN1: EURO_PWR_2x5; PinHeader_2x05_P2.54mm_Vertical
R44, R47: 6.8K; R_0603_1608Metric_Pad1.05x0.95mm_HandSolder
R45: 100K; R_0603_1608Metric_Pad1.05x0.95mm_HandSolder
R46: 3.3K; R_0603_1608Metric_Pad1.05x0.95mm_HandSolder
U1, U2, U4, U5: TL074; SOIC-14_3.9x8.7mm_P1.27mm
U3: V2164; SOIC-16_3.9x9.9mm_P1.27mm

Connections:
0.16V_REF: C15.1, R45.2, R46.1; also elsewhere on the board
5V_REF: C14.1, D4.1 (K), R44.2, R45.1; also elsewhere on the board
+12V: C16.1, C19.1, C21.1, C23.1, C25.1, C27.1, D5.3 (+), R44.1, U1.4 (V+), U2.4 (V+), U3.16 (V+), U4.4 (V+), U5.4 (V+)
-5V_REF: C18.1, D6.2 (A), R47.2; also elsewhere on the board
-12V: C17.2, C20.2, C22.2, C24.2, C26.2, C28.2, D5.4 (-), R47.1, U1.11 (V-), U2.11 (V-), U3.9 (-V), U4.11 (V-), U5.11 (V-); also elsewhere on the board
GND: C14.2, C15.2, C16.2, C17.1, C18.2, C19.2, C20.1, C21.2, C22.1, C23.2, C24.1, C25.2, C26.1, C27.2, C28.1, D4.2 (A), D6.1 (K), PWR_IN1.3 (GND), PWR_IN1.4 (GND), PWR_IN1.5 (GND), PWR_IN1.6 (GND), PWR_IN1.7 (GND), PWR_IN1.8 (GND), R46.2, U3.8 (GND); also elsewhere on the board
unnamed: D5.1 (~~), F2.1
unnamed: D5.2 (~~), F1.1
unnamed: F1.2, PWR_IN1.1 (+12V), PWR_IN1.2 (+12V)
unnamed: F2.2, PWR_IN1.9 (-12V), PWR_IN1.10 (-12V)

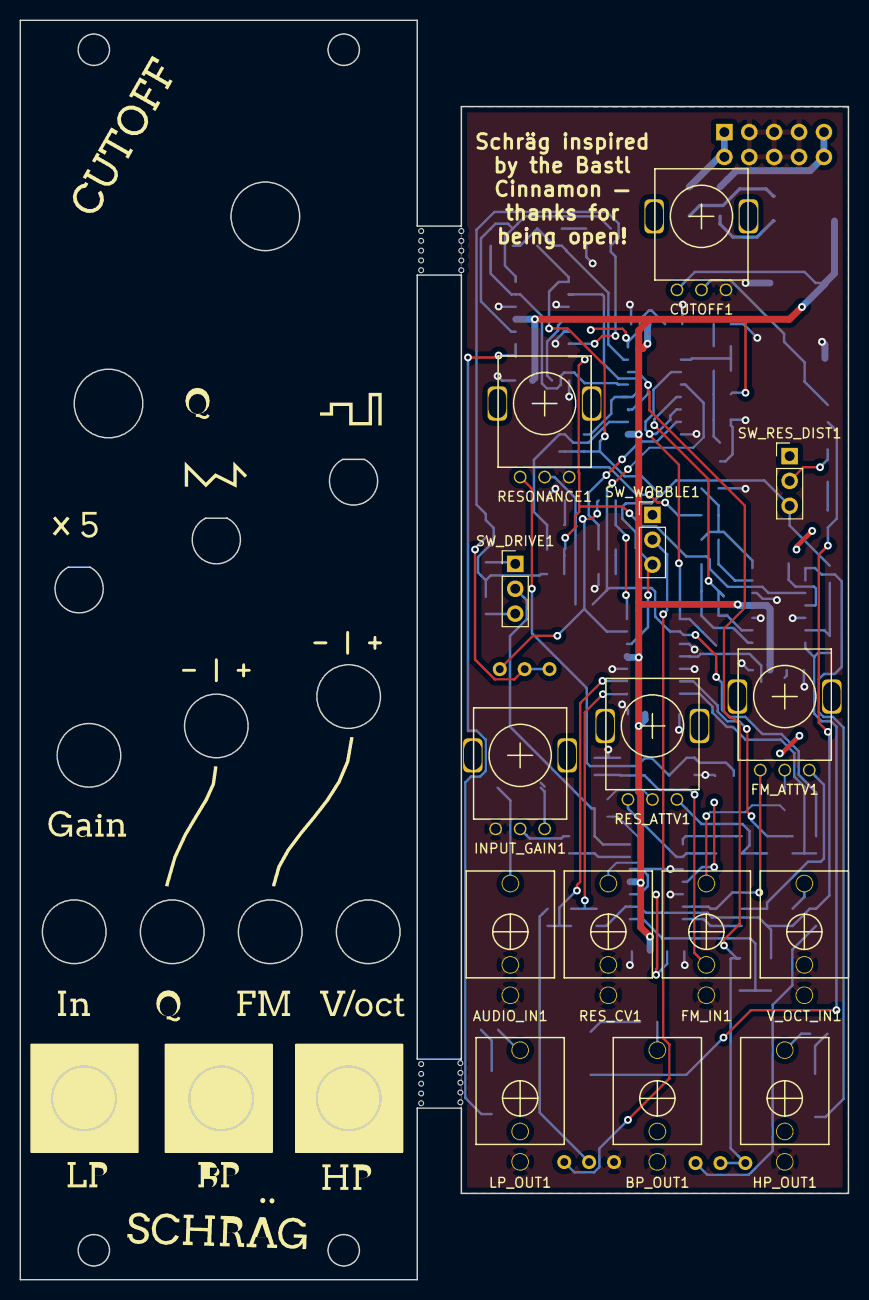
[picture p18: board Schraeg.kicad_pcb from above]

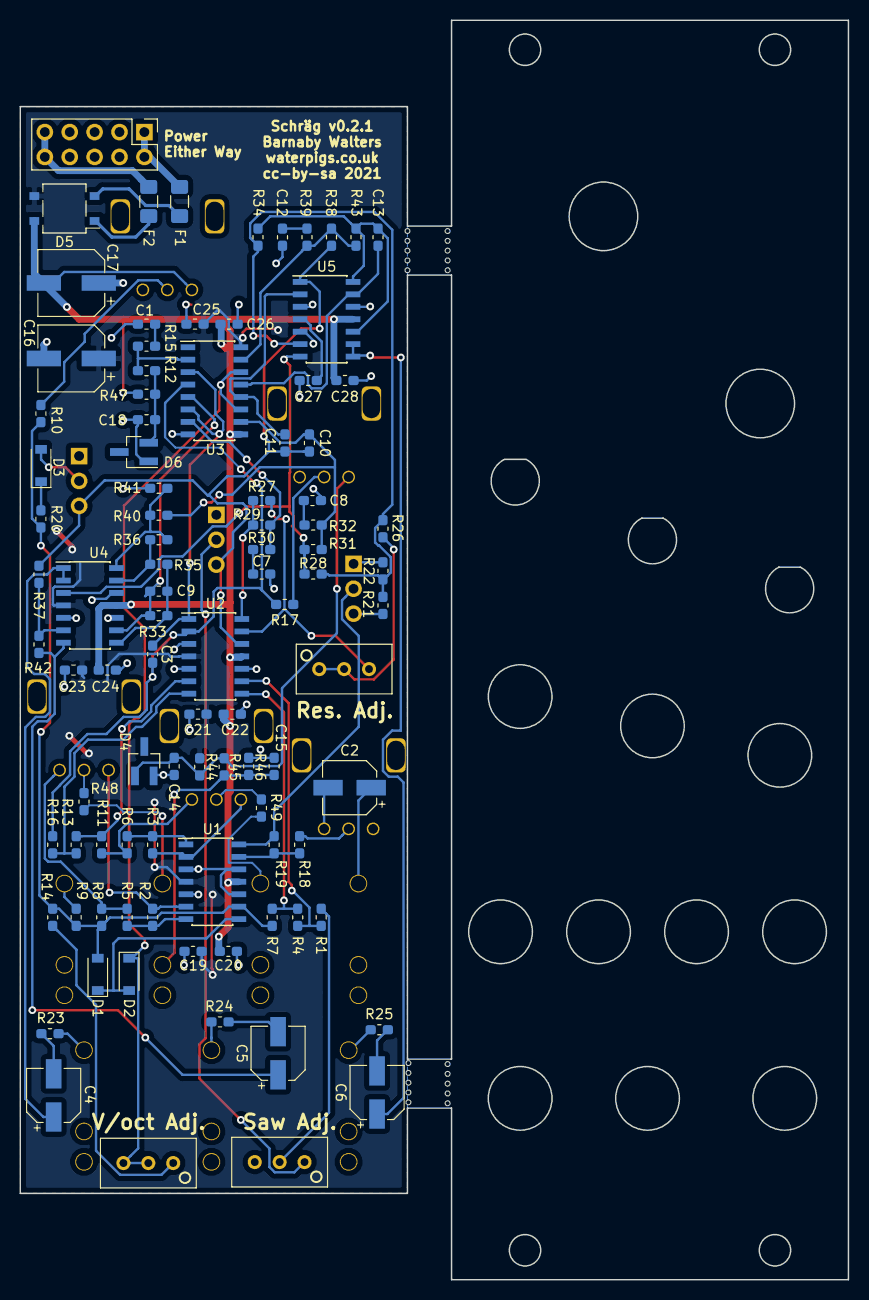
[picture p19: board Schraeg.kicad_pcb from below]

Board: 2 copper layers, 84.5 x 128.5 mm, 116 parts (94 on the bottom side), 75 nets.

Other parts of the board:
MOUSEBITE1mm, MOUSEBITE1mm#2, MOUSEBITE1mm#3, MOUSEBITE1mm#4: VAL**; MOUSEBITE1mm
Ref**: Val**; Schraeg Panel Graphics Inkscape
Ref**#2: Val**; Schraeg Panel Graphics Inkscape
svg2mod: G***; Schraeg Panel Graphics Inkscape

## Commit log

2021-01-15 Initial commit
    2019 edition board with fixed attenuverter input resistors, voltage
    reference footprints.
    [Schraeg Panel Graphics 40.64 x 128.5.dxf, Schraeg Panel Graphics.dxf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]
2021-01-15 Finished v0.2
    * Flipped switches
    * Enlarged switch holes
    * Enlarged and enovaled pot support holes
    * Reduced jack socket hole sizes
    * Improved component and component reference locations
    Archived v0.1 (previously know as the 2019 edition) and
    re-exported schematics, gerbers, interactive BOM etc for
    the 2021 Edition (v0.2).
    [Schraeg-B.Cu.gbl, Schraeg-B.Mask.gbs, Schraeg-B.SilkS.gbo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]
2021-01-18 Added README, License, BOM
    [Schraeg BOM.csv]
2021-01-18 Moved link to interactive BOM to features section
2021-01-18 Update README.md
    Mentioned that the boards are laid out using KiCAD
2021-05-28 Fixed LM4040 symbols and PCB layout. Fixes #2
    [Schraeg-B.Cu.gbl, Schraeg-B.Mask.gbs, Schraeg-B.SilkS.gbo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]
2021-05-28 Updated board version reference
    [Schraeg.kicad_pcb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]
